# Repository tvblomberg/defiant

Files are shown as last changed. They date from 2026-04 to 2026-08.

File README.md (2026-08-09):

# Defiant

A 36-key wireless split keyboard inspired by the ZSA Voyager and GEIST Totem.

## Design Goals

- 36 keys (5 columns x 3 rows + 1 side key + 2 thumb keys per half)
- MX key spacing (19.05mm)
- Choc switches with hotswap sockets
- Wireless split via Seeed XIAO nRF52840
- ZMK firmware
- 3D printed case
- Ergogen-generated PCB

## Layout

The main matrix uses a Voyager-inspired column stagger with a Totem-style outer side key. The thumb cluster is a 2-key rotated cluster.

## Versions

Each hardware revision lives in its own self-contained directory:

- `v1/` — first release (built 2026-04-19): Choc switches, nice!nano v2, no display, ~110 mAh battery
- `v2/` — adds nice!view per-half display, 750 mAh battery, canonical MCU-on-top assembly

All commands below run from inside the version directory you're working on (e.g. `cd v1`).

### v2 assembly notes

- **nice!nano**: socketed via Mill-Max headers, mounted on the **F (top)** side. Bridge the F-side MCU jumpers.
- **Switches, hotswaps, diodes, JST connector, power switch, reset switch**: all on the **B (bottom)** side.
- **Battery**: 750 mAh 403450 LiPo (4 × 34 × 50 mm). Sits below the PCB inside a case cavity — case must accommodate the keep-out.
- **nice!view display**: mounted on F (top), anchored at the same point as the MCU so the display's pin row sits dead-center over the nano body. SPI uses D5/D6/D7 for CS/MOSI/SCK (custom overlay; the upstream `nice_view_adapter` would collide with the matrix columns). Charge status is read off the on-screen battery widget.

## Building

### Prerequisites

- Node.js
- OpenSCAD (for test plate STL export)
- KiCad 8 (for PCB editing)

### Generate Ergogen output

```bash
cd v1
npm install
npx ergogen . -o output --debug
```

### Generate test plate

```bash
cd v1
python3 generate_plate.py
```

Opens `output/test_plate.scad` in OpenSCAD to export STL for 3D printing.

## Project Structure

```
.github/workflows/   # ZMK firmware CI (per-version build job)
freerouting.jar      # Shared autorouter (gitignored)
v1/
  config.yaml        # Ergogen keyboard layout definition
  generate_plate.py  # Test plate generator
  footprints/        # Ergogen footprint submodules (pinned per version)
  firmware/          # ZMK shield + build matrix
  releases/          # Tagged PCB releases
  output/            # Generated files (gitignored)
```

## License

This project is licensed under [CC BY-NC-SA 4.0](LICENSE). You are free to build one for personal use, but commercial sale is not permitted.

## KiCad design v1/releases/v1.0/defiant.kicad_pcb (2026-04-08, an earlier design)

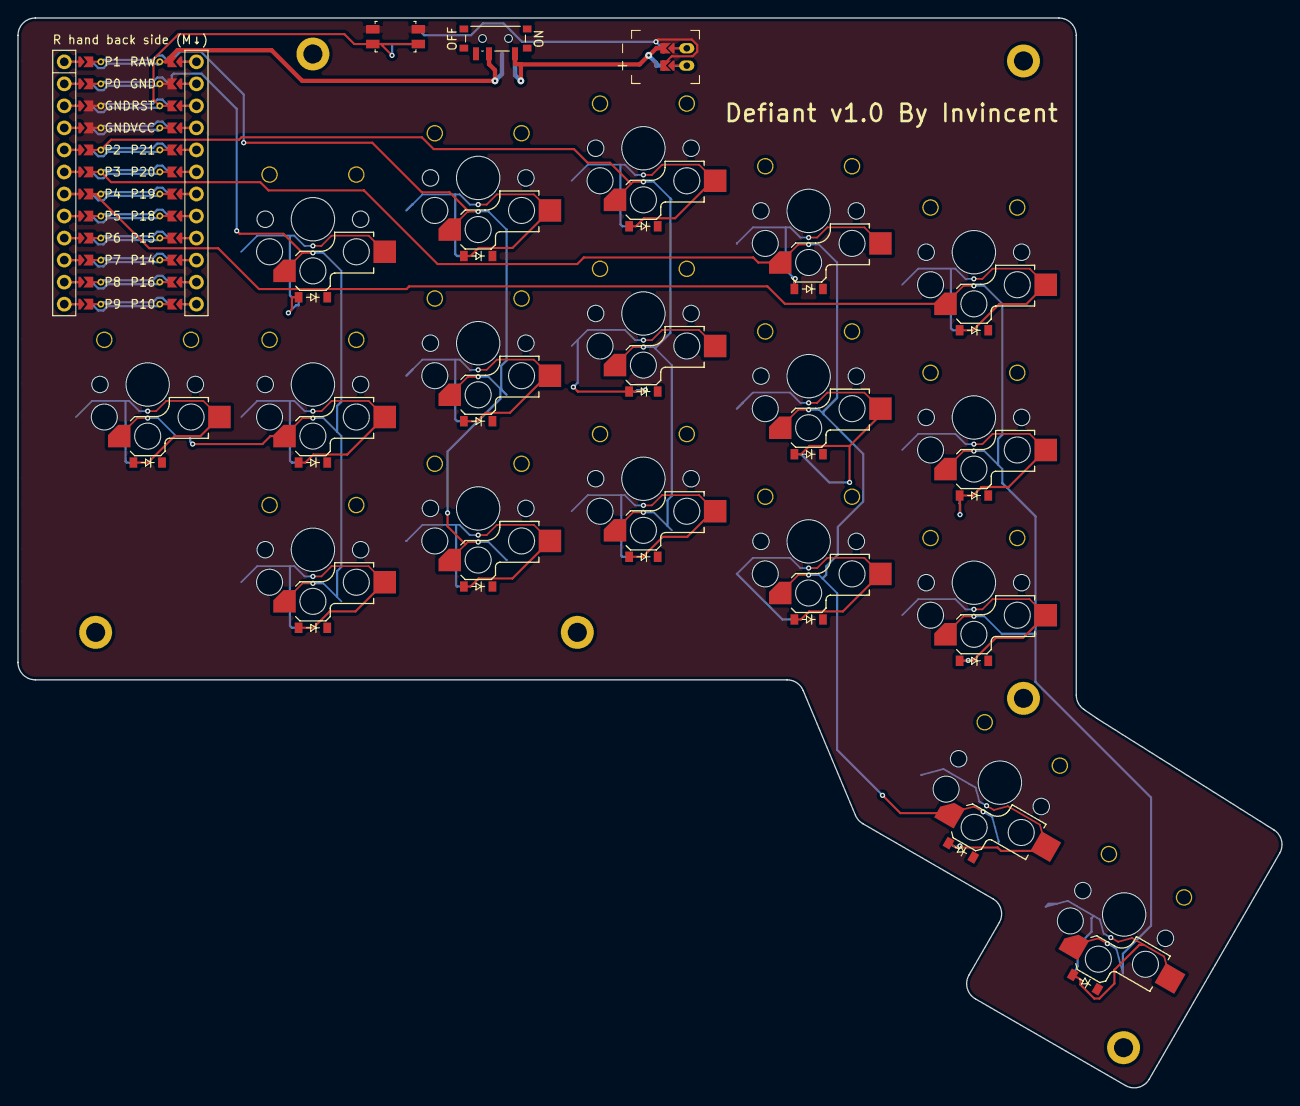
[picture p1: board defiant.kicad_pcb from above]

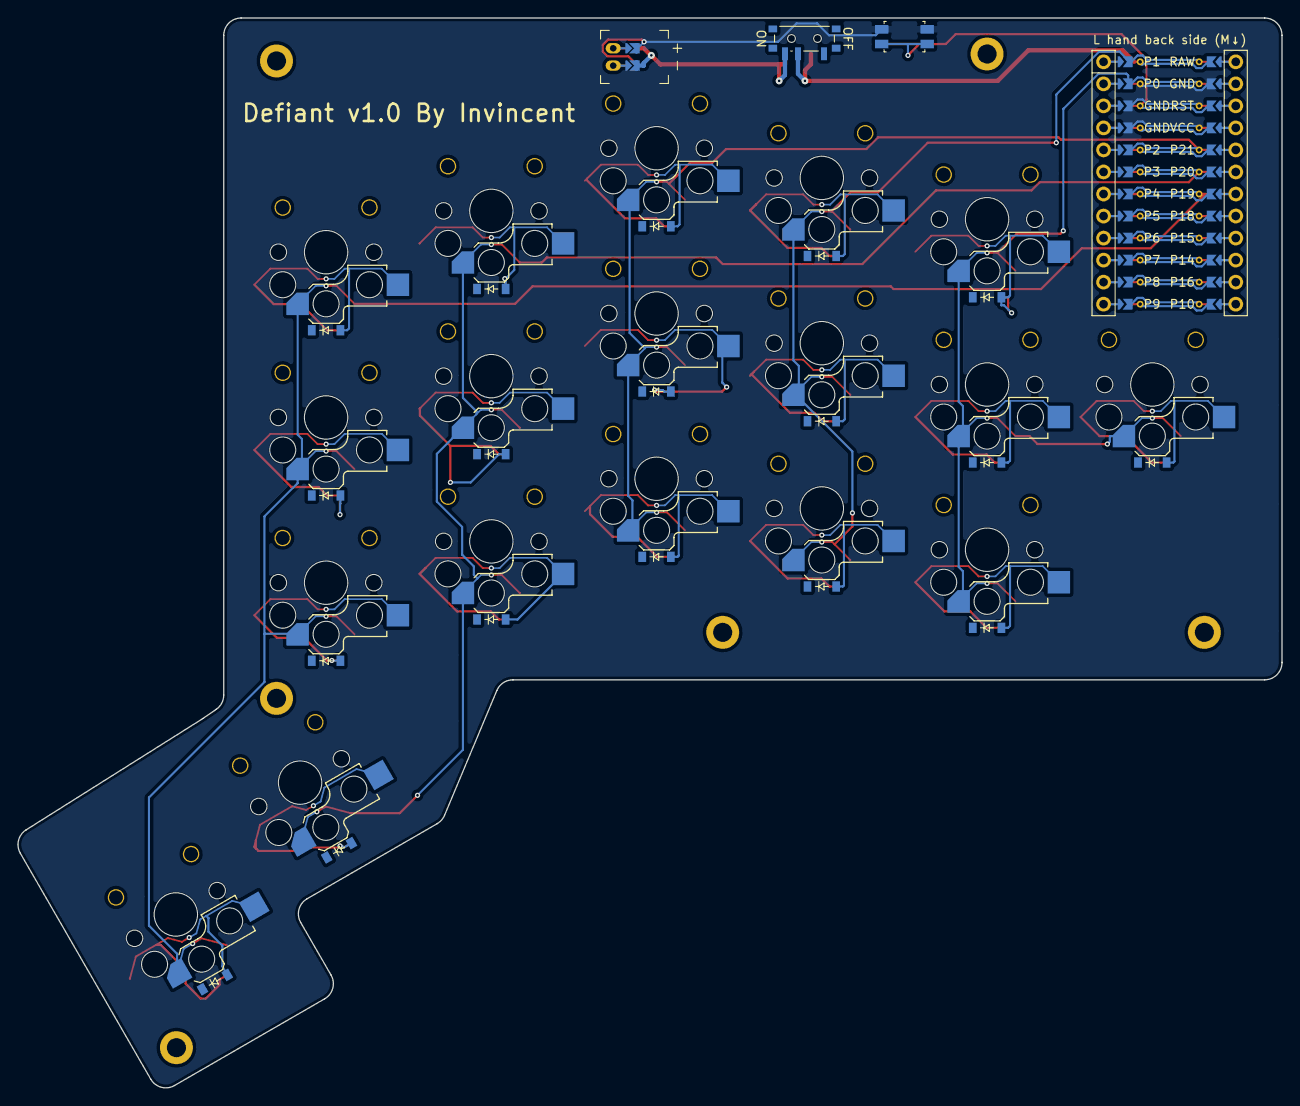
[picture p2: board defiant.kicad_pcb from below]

Board: 2 copper layers, 145.7 x 123.3 mm, 46 parts (18 on the bottom side), 29 nets.

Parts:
D1, D2, D3, D4, D5, D6, D7, D8, D9, D10, D11, D12, D13, D14, D15, D16, D17, D18: diode_tht_sod123
H1, H2, H3, H4, H5, H6: mounting_hole_plated
JST1: battery_connector_jst_ph_2
MCU1: mcu_nice_nano
PWR1: power_switch_smd_side
RST1: reset_switch_smd_side
S1, S2, S3, S4, S5, S6, S7, S8, S9, S10, S11, S12, S13, S14, S15, S16, S17, S18: switch_choc_v1_v2

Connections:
BAT_P: JST1.1, PWR1.1, PWR1.3
GND: JST1.2, MCU1.102, MCU1.121, MCU1.122, RST1.1, RST1.3
JST1_1: JST1.11, JST1.21, JST1.31
JST1_2: JST1.12, JST1.22, JST1.32
P0: MCU1.123, S1.1, S2.1, S3.1, S16.1
P1: MCU1.124, S4.1, S5.1, S6.1
P2: MCU1.120, S7.1, S8.1, S9.1
P3: MCU1.119, S10.1, S11.1, S12.1, S17.1
P4: MCU1.118, S13.1, S14.1, S15.1, S18.1
RAW: MCU1.101, PWR1.2
RST: MCU1.103, RST1.2, RST1.4
far_thumb: D18.2, S18.2
index_bottom: D10.2, S10.2
index_home: D11.2, S11.2
index_top: D12.2, S12.2
inner_bottom: D13.2, S13.2
inner_home: D14.2, S14.2
inner_top: D15.2, S15.2
middle_bottom: D7.2, S7.2
middle_home: D8.2, S8.2
middle_top: D9.2, S9.2
near_thumb: D17.2, S17.2
outer_default: D16.2, S16.2
pinky_bottom: D1.2, S1.2
pinky_home: D2.2, S2.2
pinky_top: D3.2, S3.2
ring_bottom: D4.2, S4.2
ring_home: D5.2, S5.2
ring_top: D6.2, S6.2

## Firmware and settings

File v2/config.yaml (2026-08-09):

units:
  # MX spacing
  kx: 19.05
  ky: 19.05
  # Padding for board outline
  px: kx + 4
  py: ky + 4

points:
  key:
    spread: kx
    padding: ky
    tags:
      key: true

  zones:
    # Main 5x3 matrix - Voyager stagger
    # Columns P0-P4 (left side of nice!nano)
    # Rows P19-P21, P10 (right side of nice!nano) for better routing
    # R3 (P10) is used for side key and thumb keys
    matrix:
      anchor:
        shift: [100, -200]
      columns:
        pinky:
          key.column_net: P0
        ring:
          key.stagger: 0.25 ky
          key.column_net: P1
        middle:
          key.stagger: 0.25 ky - 1.34
          key.column_net: P2
        index:
          key.stagger: -0.25 ky - 2.46
          key.column_net: P3
        inner:
          key.stagger: -0.25 ky
          key.column_net: P4
      rows:
        bottom:
          row_net: P19
        home:
          row_net: P20
        top:
          row_net: P21

    # Totem-style side key (outer pinky)
    # Shares column P0 with pinky, uses dedicated row P9
    # (P9 is bottom-left of nice!nano, physically near the side key)
    side:
      anchor:
        ref: matrix_pinky_home
        shift: [-kx, 0]
      columns:
        outer:
          key.column_net: P0
      rows:
        default:
          row_net: P9
      key.tags:
        key: true
        side: true

    # Thumb cluster - 2 keys
    # near shares column P3 (index), far shares column P4 (inner)
    # Both use row P10 (R3)
    thumb:
      anchor:
        ref: matrix_inner_bottom
        shift: [3, -kx - 4]
        rotate: -30
      columns:
        near:
          key.column_net: P3
        far:
          key.spread: 20
          key.stagger: -6
          key.width: 1.5 kx
          key.column_net: P4
      rows:
        thumb:
          row_net: P10
      key.tags:
        key: true
        thumb: true

outlines:
  # Key switch cutouts (MX plate cutout = 14mm)
  _keys:
    - what: rectangle
      where: key
      size: [14, 14]

  # Keycap outlines
  _caps:
    - what: rectangle
      where: key
      size: [18, 18]
    - what: rectangle
      where: /^thumb_far/
      size: [18, 1.5 ky - 1]
      operation: stack

  # Keycaps only
  preview_caps:
    - what: outline
      name: _caps

  # Switches only
  preview_switches:
    - what: outline
      name: _keys

  # Both layers combined
  preview:
    - what: outline
      name: _caps
    - what: outline
      name: _keys
      operation: stack
  raw:
  - what: rectangle
    where: true
    size: [px, py]
  board:
  - what: polygon
    operation: stack
    fillet: 2
    points:
      # All points relative to matrix_pinky_bottom (100, -200)
      # Key positions: side(80.95,-180.95) pinky_top(100,-161.9)
      #   middle_top(157.2,-153.71) inner_top(195.2,-165.7)
      #   inner_bottom(195.2,-203.8) pinky_bottom(100,-200)
      #   thumb_near(198.2,-226.85,r-30) thumb_far(212.6,-242.05,r-30)
      #
      # Padding: 12mm from key centers (~half key + 3mm)
      #
      # 1. Top-left (3mm from keycap edges)
      - ref: matrix_pinky_bottom
        shift: [-34, 66.5]
      # 2. Top-right
      - ref: matrix_pinky_bottom
        shift: [88, 66.5]
      # 3. Right side down to inner bottom
      - ref: matrix_pinky_bottom
        shift: [88, -17.8]
      # 4. Into thumb - right side of near thumb
      - ref: thumb_near_thumb
        shift: [6, 12]
      # 5. Right side of far thumb (extra padding for 1.5u height)
      - ref: thumb_far_thumb
        shift: [12, 17]
      # 6. Bottom of far thumb
      - ref: thumb_far_thumb
        shift: [12, -17]
      # 7. Left of far thumb
      - ref: thumb_far_thumb
        shift: [-12, -17]
      - ref: thumb_far_thumb
        shift: [-12, -6]
      # 8. Left of near thumb
      - ref: thumb_near_thumb
        shift: [-12, -12]
      # 9. Bottom-right of main body (3mm from keycap edges)
      - ref: matrix_pinky_bottom
        shift: [56, -15]
      # 10. Bottom-left
      - ref: matrix_pinky_bottom
        shift: [-34, -15]
  combo:
    - name: board
    - operation: subtract
      name: preview_caps
  plate:
    - name: board
    - operation: subtract
      name: _keys
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

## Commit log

2026-03-30 Initial commit: Ergogen layout for Defiant keyboard
    Voyager-inspired 36-key split wireless layout with Totem-style
    side key, MX spacing, and test plate generator for verification.
2026-03-31 Add PCB scaffold with components, board outline, and optimized matrix
    - Added Choc hotswap switch, diode, XIAO nRF52840, battery connector,
    power switch, and reset button footprints via Ergogen
    - Optimized key matrix from 13 nets to 9 (6 cols x 3 rows) to fit
    within XIAO's 11 GPIO pins
    - Refined column stagger based on physical measurements
    - Added Voyager-style board outline with thumb cluster extension
    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
2026-03-31 More board tweaking
2026-04-08 Version 1 of the keyboard
    [defiant.kicad_pcb]
2026-04-17 Add ZMK firmware and v1.1 release
    - Fix critical Ergogen row_net bug: use `row_net:` not `key.row_net:`
    in row definitions so {{row_net}} resolves in diode footprints
    - Update silkscreen text to v1.1
    - Save v1.1 gerbers and routed PCB for manufacturing record
    - Add ZMK firmware under firmware/ subfolder:
    - Matrix transform (10 cols x 5 rows) for split keyboard with shared
    columns on P0/P3/P4 and dedicated rows for side key (P9) and thumbs (P10)
    - Right-half overlay reverses col-gpios to handle flipped PCB
    - 6-layer keymap replicating QSA Voyager freya36 QMK setup:
    base (QWERTY + HRM), mouse, symbols, nav, function, workspace macros
    - urob-style "timeless" HRM with opposite-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
    [defiant.kicad_pcb]
2026-04-17 Fix west.yml self.path for nested firmware/config location
    GitHub Actions was failing because west inferred the workspace root
    as firmware/ (matching self.path: config) instead of the repo root.
    This caused a mismatch with the workflow's base_dir (repo root),
    so zephyr couldn't be found and west boards failed.
    Setting self.path to "firmware/config" aligns west's workspace root
    with the repo root where the workflow runs.
2026-04-17 Update board name for Zephyr 4.1 compat
    ZMK 4.1+ no longer accepts 'nice_nano_v2'. Board variants moved to
    <board>/<soc>/<variant> format. Use 'nice_nano/nrf52840/zmk' which
    defaults to revision 2.0.0 (v2).
    See https://zmk.dev/blog/2025/12/09/zephyr-4-1
2026-04-17 Enable pointing feature for mouse layer bindings
    The &mkp behavior and LCLK/RCLK/MCLK keycodes require:
    - #include <dt-bindings/zmk/pointing.h> in the keymap
    - CONFIG_ZMK_POINTING=y in the .conf
    Without these, the devicetree parser sees LCLK as an undefined
    identifier and fails with "expected number or parenthesized expression".
2026-04-17 Include physical_layouts.dtsi for &key_physical_attrs label
    The &key_physical_attrs reference requires the physical_layouts.dtsi
    header which defines it. Without this include the device tree parser
    reports: undefined node label 'key_physical_attrs'.
2026-04-19 Swap P0/P1 col-gpios to match PCB routing
    Left pinky/ring columns were swapped. The PCB routes P1 to the pinky
    column and P0 to the ring column, opposite of the Ergogen labels.
2026-04-19 Add BLE controls to Macros layer and mouse movement to Mouse layer
    Macros layer top row now binds BT_CLR, BT_SEL 0-4, and OUT_USB/OUT_BLE/OUT_TOG
    so the keyboard can switch BLE profiles and toggle USB/BLE output without Studio.
    Mouse layer gets IJKL-style cursor movement, page up/down, and a middle-click
    on the left thumb-far key. Matches the Voyager QMK mouse layer.
2026-04-19 Convert q/p morph to hold-tap so shift+Q produces capital Q
    The mod-morph triggered on shift-held, so typing a capital Q fired
    the lock-screen shortcut. Switching to a tap-preferred hold-tap means
    shift+Q types Q normally and only a deliberate hold triggers the
    GUI+shift+Q / GUI+P shortcut.
2026-04-19 Parameterize q/p hold-tap, drop unused macros
    ZMK's hold-tap schema mandates #binding-cells = 2. Switch to a single
    generic hold-tap and pass the hold/tap keycodes at the usage site.
2026-04-20 Shorten sleep timeout to 5 min and drop +8 dBm TX boost
    110 mAh batteries benefit from aggressive idle sleep and default BLE
    TX power. The +8 dBm setting quadrupled radio power for range that
    isn't needed at desk distance, eating battery on every packet.
2026-04-25 Reorganize into v1/ subdir to support multiple hardware revisions
    Each hardware version becomes a self-contained directory holding its own
    Ergogen config, footprint submodule pins, ZMK shield, and releases. v2
    work can branch from a copy of v1/ without disturbing the shipped design.
    [defiant.kicad_pcb]
2026-08-09 Mark kscan as wakeup-source so deep sleep engages
    The kscan node was missing `wakeup-source;`, which keeps the row GPIO
    interrupts armed while the SoC is powered down. Without it the deep-sleep
    state never delivered its ~20 uA: an idle 71-minute window drew ~2.8 mA
    average, roughly 30x what it should have.
    ZMK's stock shields (corne, lily58) declare it on an otherwise identical
    kscan node.
2026-08-09 Set west self.path to the full path from the repo root
    West derives its topdir by stripping self.path off the manifest directory.
    With a bare "config", `west init -l v1/firmware/config` put the workspace at
    v1/firmware/ and cloned zmk/ and zephyr/ there, while ZMK's build-user-config
    workflow keeps using the repo root as its base_dir and looks for them at
    ${base_dir}/zmk/app. Zephyr's west extension commands never registered, so the
    board-qualifier step died on `west: unknown command "boards"`.
    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
2026-08-09 Add v2 hardware revision and firmware config
    Brings the in-progress v2 work under version control so CI can build it:
    Ergogen config, plate generator, footprint submodules, and a ZMK shield
    carrying the per-half nice!view display.
    The v2 shield defines its own nice_view_spi on D5/D6/D14 rather than using
    the upstream nice_view_adapter, whose D1/D2/D3 pinout collides with the
    matrix. Its kscan carries the same wakeup-source fix as v1, and its west
    manifest names the full path from the repo root for the same reason.
    [config.yaml]
2026-08-10 Move ZMK configs to config-v1/ and config-v2/ at the repo root
    `west init -l <dir>` sets topdir to <dir>'s parent and ignores the manifest's
    self.path entirely:
    abs_manifest_path = Path(args.directory or os.getcwd()).resolve()
    topdir = Path(args.topdir or abs_manifest_path.parent).resolve()
    ZMK's build-user-config workflow runs both `west init -l ${base_dir}/${config_path}`
    and `west update` from ${base_dir} (the repo root), so .west/ has to land at the
    repo root for update to find it. With the config three levels down the workspace
    was created at v1/firmware/ and every build died -- first on `west: unknown
    command "boards"`, then on `no west workspace found`.
    That makes a config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
2026-08-10 Split v1 and v2 builds into separate workflow files
    ZMK's build-user-config uploads each matrix job as `artifact-<artifact_name>`,
    derived from board and shield only, then merges with:
    pattern: artifact-*
    delete-merged: true
    Artifact names are scoped to the workflow run, not the job, so calling the
    reusable workflow twice from one file put both revisions' firmware in a single
    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
